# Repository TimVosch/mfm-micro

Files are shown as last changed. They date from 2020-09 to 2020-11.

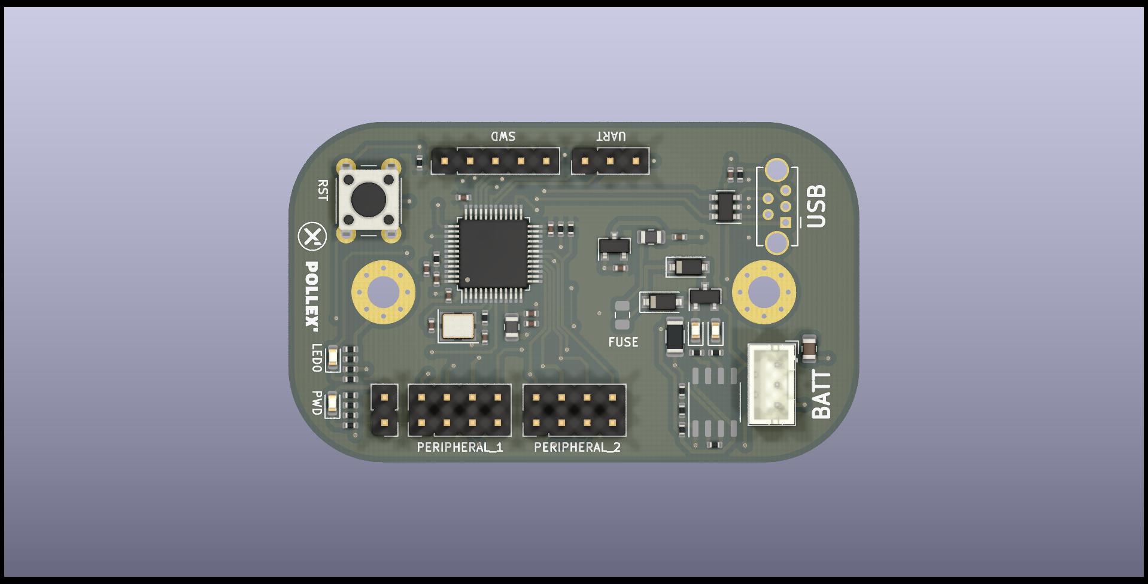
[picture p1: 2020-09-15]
hardware/export/pcb_front.jpg

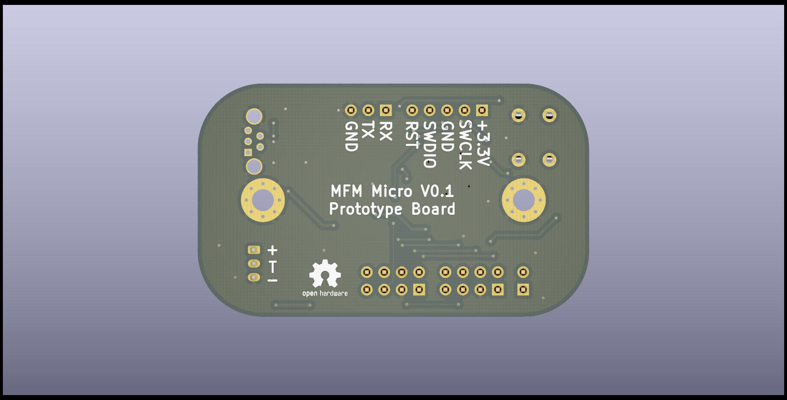
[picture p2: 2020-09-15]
hardware/export/pcb_back.jpg

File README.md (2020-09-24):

# Multiflexmeter Micro

A small, long lasting measurement device with hotswappable zero-configuration peripherals.

## Hardware development

Developed using KiCAD. Files are in the `hardware` folder.

## Firmware development

Developed using PlatformIO and the STM32CubeL0 library with CMSIS.

```
git clone https://github.com/TimVosch/mfm-micro.git
cd mfm-micro
git submodule update --init
```

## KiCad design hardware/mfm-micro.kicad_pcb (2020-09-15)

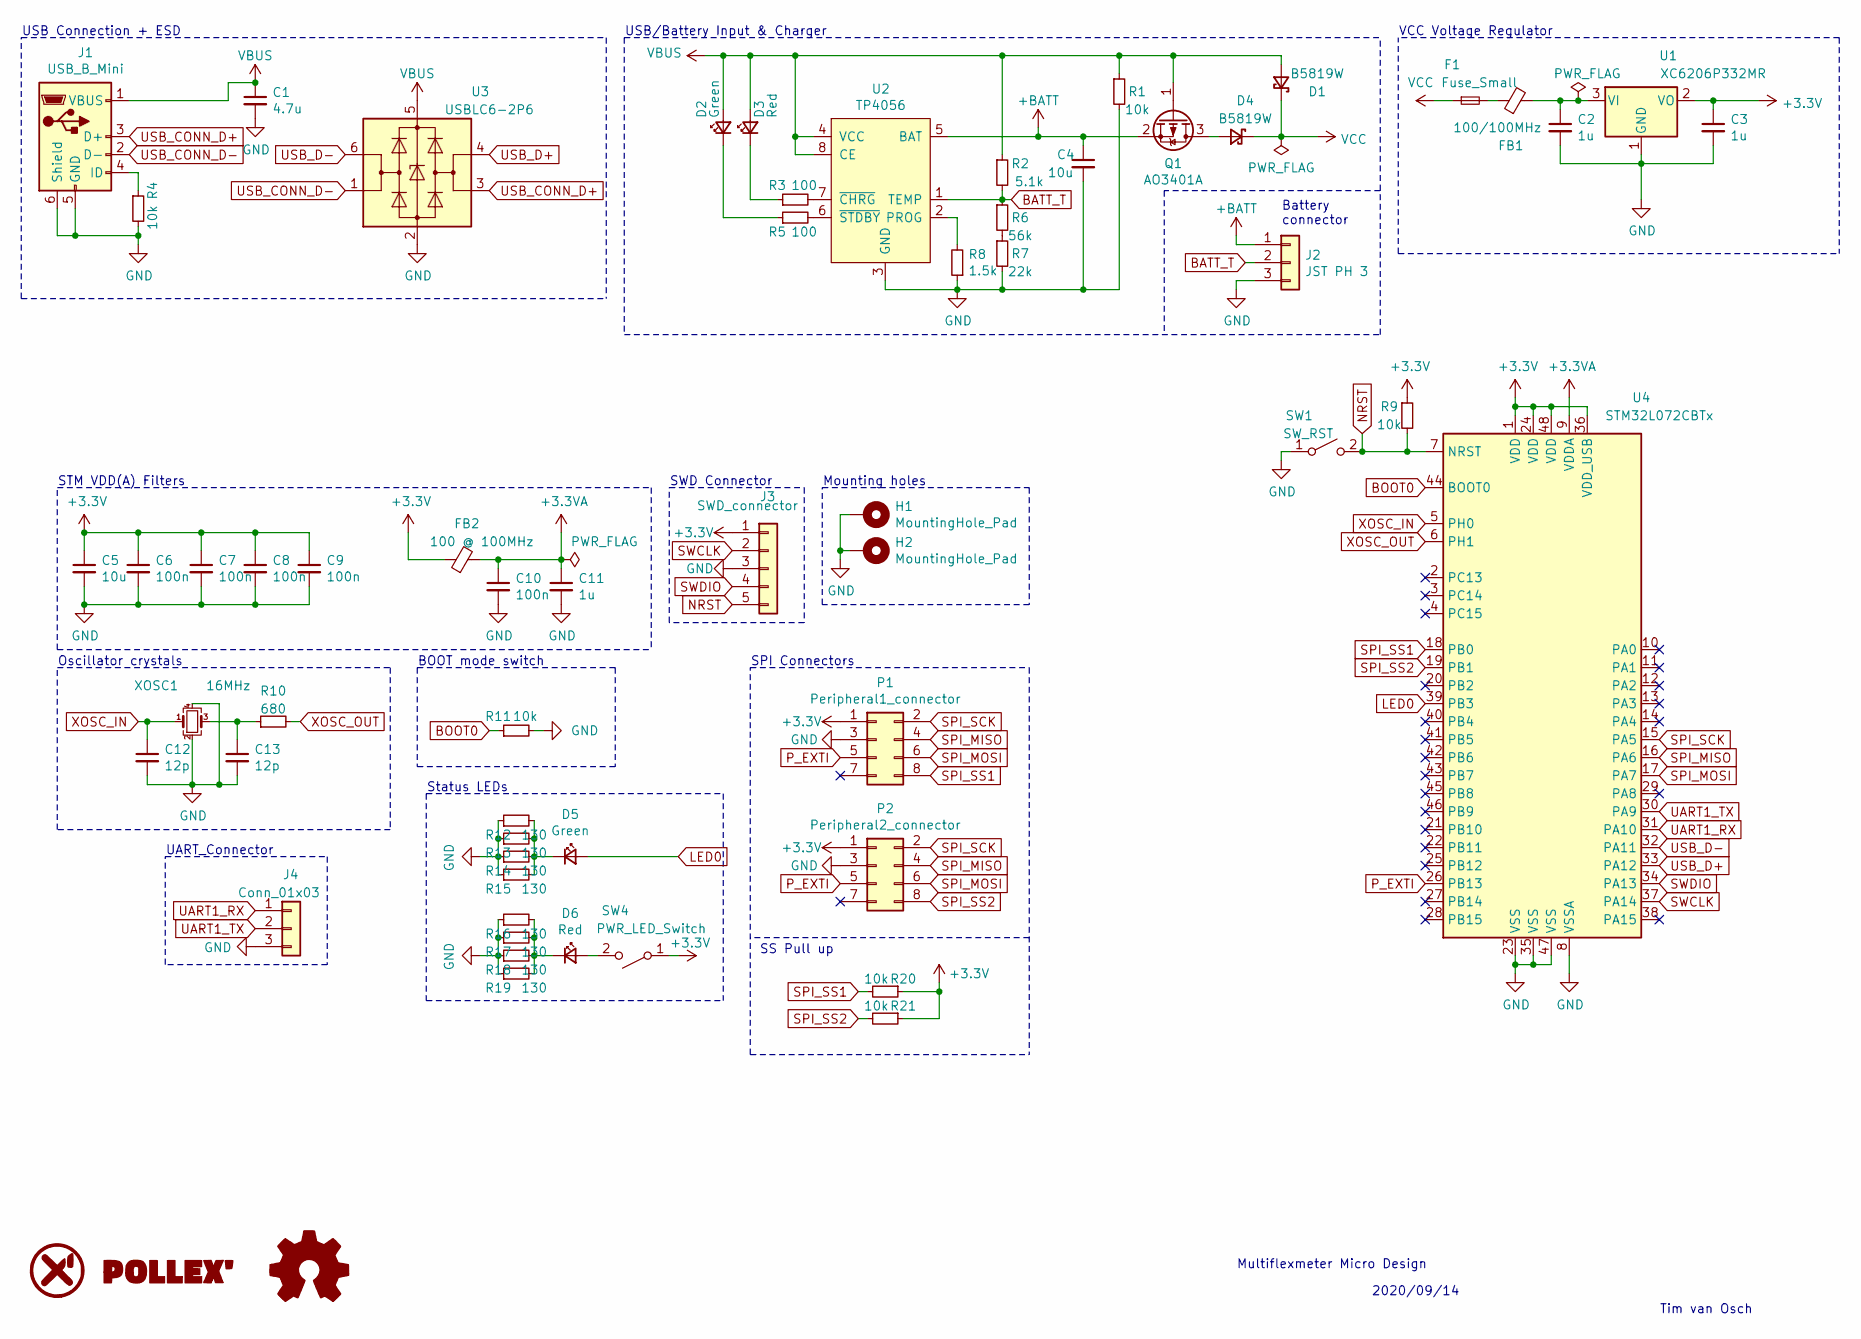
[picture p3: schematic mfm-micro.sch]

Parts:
C1: 4.7u; C_0402_1005Metric
C2, C3, C11: 1u; C_0402_1005Metric
C4: 10u; C_0805_2012Metric
C5: 10u; C_0402_1005Metric
C6, C7, C8, C9, C10: 100n; C_0402_1005Metric
C12, C13: 12p; C_0402_1005Metric
D1, D4: B5819W; D_SOD-123
D2, D5: Green; LED_0603_1608Metric
D3, D6: Red; LED_0603_1608Metric
F1: Fuse_Small; Fuse_0805_2012Metric
FB1: 100/100MHz; L_0805_2012Metric
FB2: 100 @ 100MHz; L_0805_2012Metric
H1, H2: MountingHole_Pad; MountingHole_3.2mm_M3_Pad_Via
J1: USB_B_Mini; USB_Mini-B_Tensility_54-00023_Vertical_CircularHoles
J2: JST PH 3; JST_PH_B3B-PH-K_1x03_P2.00mm_Vertical
J3: SWD_connector; PinHeader_1x05_P2.54mm_Vertical
J4: Conn_01x03; PinHeader_1x03_P2.54mm_Vertical
P1: Peripheral1_connector; PinHeader_2x04_P2.54mm_Vertical
P2: Peripheral2_connector; PinHeader_2x04_P2.54mm_Vertical
Q1: AO3401A; SOT-23
R1: 10k; R_1206_3216Metric
R2: 5.1k; R_0402_1005Metric
R3, R5: 100; R_0402_1005Metric
R4, R9, R11, R20, R21: 10k; R_0402_1005Metric
R6: 56k; R_0402_1005Metric
R7: 22k; R_0402_1005Metric
R8: 1.5k; R_0402_1005Metric
R10: 680; R_0402_1005Metric
R12, R13, R14, R15, R16, R17, R18, R19: 130; R_0402_1005Metric
SW1: SW_RST; SW_PUSH_6mm
SW4: PWR_LED_Switch; PinHeader_1x02_P2.54mm_Vertical
U1: XC6206P332MR; SOT-23
U2: TP4056; SOP-8_3.9x4.9mm_P1.27mm
U3: USBLC6-2P6; SOT-23-6
U4: STM32L072CBTx; LQFP-48_7x7mm_P0.5mm
XOSC1: 16MHz; Crystal_SMD_3225-4Pin_3.2x2.5mm

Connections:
+3.3VA: C10.1, C11.1, FB2.2, U4.9 (VDDA)
+3V3: C3.1, C5.1, C6.1, C7.1, C8.1, C9.1, FB2.1, J3.1, P1.1, P2.1, R9.1, R20.1, R21.1, SW4.1 (A), U1.2 (VO), U4.1 (VDD), U4.24 (VDD), U4.36 (VDD_USB), U4.48 (VDD)
+BATT: C4.1, J2.1, Q1.2 (S), U2.5 (BAT)
BATT_T: J2.2, R2.2, R6.1, U2.1 (TEMP)
BOOT0: R11.1, U4.44 (BOOT0)
GND: C1.2, C2.2, C3.2, C4.2, C5.2, C6.2, C7.2, C8.2, C9.2, C10.2, C11.2, C12.2, C13.2, H1.1, H2.1, J1.5 (GND), J1.6 (Shield), J2.3, J3.3, J4.3, P1.3, P2.3, R1.2, R4.2, R7.2, R8.1, R11.2, R12.1, R13.1, R14.1, R15.1, R16.1, R17.1, R18.1, R19.1, SW1.1 (A), U1.1 (GND), U2.3 (GND), U3.2 (GND), U4.8 (VSSA), U4.23 (VSS), U4.35 (VSS), U4.47 (VSS), XOSC1.2, XOSC1.4
LED0: D5.2 (A), U4.39 (PB3)
NRST: J3.5, R9.2, SW1.2 (B), U4.7 (NRST)
unnamed: C2.1, FB1.2, U1.3 (VI)
unnamed: C13.1, R10.1, XOSC1.3
unnamed: D2.1 (K), R5.1
unnamed: D3.1 (K), R3.1
unnamed: D4.2 (A), Q1.3 (D)
unnamed: D5.1 (K), R12.2, R13.2, R14.2, R15.2
unnamed: D6.1 (K), R16.2, R17.2, R18.2, R19.2
unnamed: D6.2 (A), SW4.2 (B)
unnamed: F1.2, FB1.1
unnamed: J1.4 (ID), R4.1
unnamed: R3.2, U2.7 (~CHRG)
unnamed: R5.2, U2.6 (~STDBY)
unnamed: R6.2, R7.1
unnamed: R8.2, U2.2 (PROG)
P_EXTI: P1.5, P2.5, U4.26 (PB13)
SPI_MISO: P1.4, P2.4, U4.16 (PA6)
SPI_MOSI: P1.6, P2.6, U4.17 (PA7)
SPI_SCK: P1.2, P2.2, U4.15 (PA5)
SPI_SS1: P1.8, R20.2, U4.18 (PB0)
SPI_SS2: P2.8, R21.2, U4.19 (PB1)
SWCLK: J3.2, U4.37 (PA14)
SWDIO: J3.4, U4.34 (PA13)
UART1_RX: J4.1, U4.31 (PA10)
UART1_TX: J4.2, U4.30 (PA9)
USB_CONN_D+: J1.3 (D+), U3.3 (I/O2)
USB_CONN_D-: J1.2 (D-), U3.1 (I/O1)
USB_D+: U3.4 (I/O2), U4.33 (PA12)
USB_D-: U3.6 (I/O1), U4.32 (PA11)
VBUS: C1.1, D1.2 (A), D2.2 (A), D3.2 (A), J1.1 (VBUS), Q1.1 (G), R1.1, R2.1, U2.4 (VCC), U2.8 (CE), U3.5 (VBUS)
VCC: D1.1 (K), D4.1 (K), F1.1
XOSC_IN: C12.1, U4.5 (PH0), XOSC1.1
XOSC_OUT: R10.2, U4.6 (PH1)

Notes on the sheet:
VCC Voltage Regulator
USB Connection + ESD
Battery connector
USB/Battery Input & Charger
SPI Connectors
Status LEDs
BOOT mode switch
Oscillator crystals
STM VDD(A) Filters
SS Pull up
Multiflexmeter Micro Design
2020/09/14
Tim van Osch
Mounting holes
SWD Connector
UART_Connector

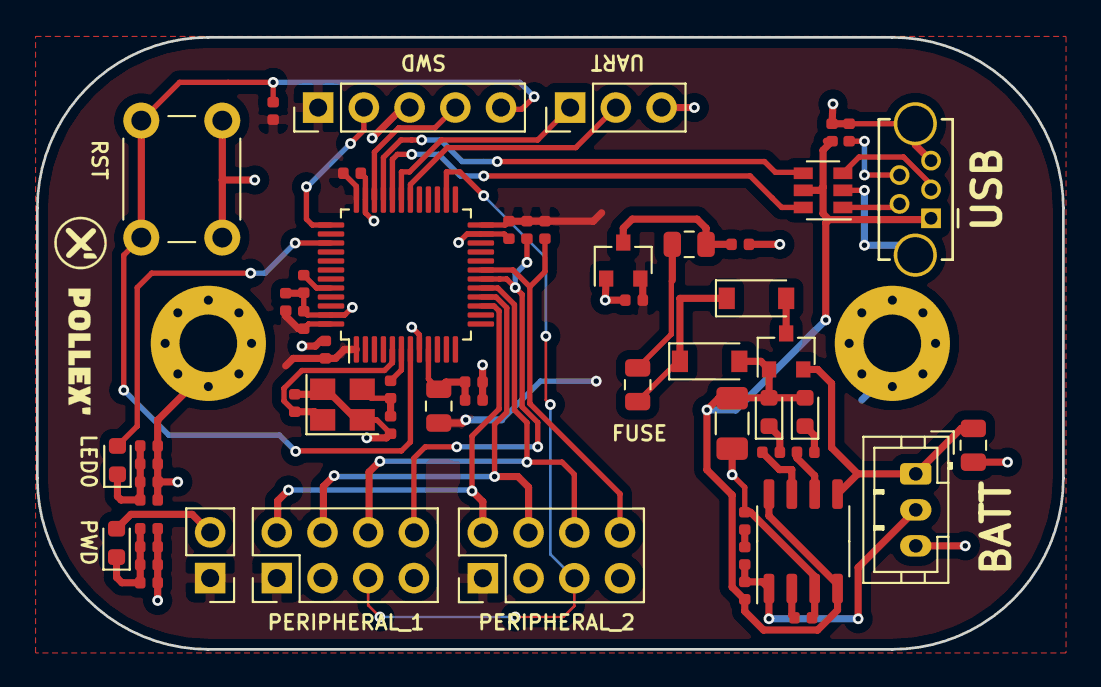
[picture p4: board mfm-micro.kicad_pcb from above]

Board: 4 copper layers, 57.0 x 34.0 mm, 59 parts (0 on the bottom side), 40 nets.

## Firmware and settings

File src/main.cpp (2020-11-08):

#include "main.hpp"
#include "drivers/i2c_timing.hpp"
#include "drivers/i2c_master.hpp"
#include "drivers/smbus.hpp"

void gpio_init()
{
  // Enable GPIO CLK
  __HAL_RCC_GPIOA_CLK_ENABLE();
  __HAL_RCC_GPIOB_CLK_ENABLE();

  GPIO_InitTypeDef GPIO_LED = {0};
  GPIO_LED.Pin = LED0_Pin;
  GPIO_LED.Mode = GPIO_MODE_OUTPUT_PP;
  GPIO_LED.Speed = GPIO_SPEED_FAST;
  GPIO_LED.Pull = GPIO_NOPULL;
  HAL_GPIO_Init(LED0_Port, &GPIO_LED);

  // ---- Initialize I2C GPIO pins ----
  // Init SCL to OpenDrain
  GPIO_InitTypeDef scl_init = {0};
  scl_init.Pin = I2C_SCL_Pin;
  scl_init.Mode = GPIO_MODE_OUTPUT_OD;
  scl_init.Speed = GPIO_SPEED_FAST;
  scl_init.Pull = GPIO_NOPULL;
  HAL_GPIO_Init(I2C_SCL_Port, &scl_init);

  // Init SDA to OpenDrain
  GPIO_InitTypeDef sda_init = {0};
  sda_init.Pin = I2C_SDA_Pin;
  sda_init.Mode = GPIO_MODE_OUTPUT_OD;
  sda_init.Speed = GPIO_SPEED_FAST;
  sda_init.Pull = GPIO_NOPULL;
  HAL_GPIO_Init(I2C_SDA_Port, &sda_init);

  // Default high
  HAL_GPIO_WritePin(I2C_SDA_Port, I2C_SDA_Pin, GPIO_PIN_SET);
  HAL_GPIO_WritePin(I2C_SCL_Port, I2C_SCL_Pin, GPIO_PIN_SET);
}

void crc_init()
{
  __HAL_RCC_CRC_CLK_ENABLE();
}

void timer_init()
{
  // Set TIMER 6 to us
  uint8_t psc = SystemCoreClock / 1e6 - 1;
  __HAL_RCC_TIM6_CLK_ENABLE();
  TIM6->SR = 0;
  TIM6->PSC = psc;
  TIM6->CR1 = TIM_CR1_UDIS;
  TIM6->CR1 = TIM_CR1_CEN;
}

/**
  * @brief System Clock Configuration
  * @retval None
  */
void SystemClock_Config(void)
{
  RCC_OscInitTypeDef RCC_OscInitStruct = {0};
  RCC_ClkInitTypeDef RCC_ClkInitStruct = {0};

  /** Configure the main internal regulator output voltage
  */
  __HAL_PWR_VOLTAGESCALING_CONFIG(PWR_REGULATOR_VOLTAGE_SCALE1);
  /** Initializes the RCC Oscillators according to the specified parameters
  * in the RCC_OscInitTypeDef structure.
  */
  RCC_OscInitStruct.OscillatorType = RCC_OSCILLATORTYPE_HSE;
  RCC_OscInitStruct.HSEState = RCC_HSE_ON;
  RCC_OscInitStruct.HSIState = RCC_HSI_OFF;
  RCC_OscInitStruct.MSIState = RCC_MSI_OFF;
  RCC_OscInitStruct.HSICalibrationValue = 0;
  RCC_OscInitStruct.PLL.PLLState = RCC_PLL_NONE;
  if (HAL_RCC_OscConfig(&RCC_OscInitStruct) != HAL_OK)
  {
    Error_Handler();
  }
  /** Initializes the CPU, AHB and APB buses clocks
  */
  RCC_ClkInitStruct.ClockType = RCC_CLOCKTYPE_HCLK | RCC_CLOCKTYPE_SYSCLK | RCC_CLOCKTYPE_PCLK1 | RCC_CLOCKTYPE_PCLK2;
  RCC_ClkInitStruct.SYSCLKSource = RCC_SYSCLKSOURCE_HSE;
  RCC_ClkInitStruct.AHBCLKDivider = RCC_SYSCLK_DIV1;
  RCC_ClkInitStruct.APB1CLKDivider = RCC_HCLK_DIV1;
  RCC_ClkInitStruct.APB2CLKDivider = RCC_HCLK_DIV1;

  if (HAL_RCC_ClockConfig(&RCC_ClkInitStruct, FLASH_LATENCY_0) != HAL_OK)
  {
    Error_Handler();
  }
  SystemCoreClockUpdate();
}

int main(void)
{
  SystemClock_Config();
  HAL_Init();
  gpio_init();
  timer_init();
  crc_init();

  I2C_TIMING standard = I2C_TIMING_STANDARD;
  I2C_Master i2c(I2C_SCL_Pin, I2C_SCL_Port, I2C_SDA_Pin, I2C_SDA_Port, &standard);
  SMBus smbus(&i2c);

  smbus.select(0x70);
  for (;;)
  {
    uint8_t data;
    auto res = smbus.receive_byte(&data);
    if (res == SMBUS_STATUS_PEC_FAIL)
    {
      HAL_GPIO_TogglePin(LED0_Port, LED0_Pin);
    }

    HAL_Delay(1000);
  }
}

void Error_Handler(void)
{
  for (;;)
    ;
}

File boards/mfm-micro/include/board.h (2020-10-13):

#if !defined(_BOARD_H_)
#define _BOARD_H_

#include <stm32l0xx_hal.h>
#include <stm32l0xx_hal_gpio.h>

/*
  Pin definitions
*/

#define LED0_Pin GPIO_PIN_3
#define LED0_Port GPIOB

/*
  Peripheral I2C definitions
*/

#define I2C_SCL_Port GPIOA
#define I2C_SCL_Pin GPIO_PIN_5
#define I2C_SDA_Port GPIOA
#define I2C_SDA_Pin GPIO_PIN_6

/*
  Peripheral SPI definitions
*/

// #define PERIPHERAL_SPI_AF GPIO_AF0_SPI1
// #define PERIPHERAL_SPI_Instance SPI1
// #define PERIPHERAL_SPI_Port GPIOA

// #define PERIPHERAL_SCK_Pin GPIO_PIN_5
// #define PERIPHERAL_MISO_Pin GPIO_PIN_6
// #define PERIPHERAL_MOSI_Pin GPIO_PIN_7

// #define PERIPHERAL_INT_Pin GPIO_PIN_13
// #define PERIPHERAL_INT_Port GPIOB

// #define PERIPHERAL1_NSS_Pin GPIO_PIN_0
// #define PERIPHERAL1_NSS_Port GPIOB

// #define PERIPHERAL2_NSS_Pin GPIO_PIN_1
// #define PERIPHERAL2_NSS_Port GPIOB

#endif

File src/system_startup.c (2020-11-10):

#include <stdint.h>
#include <stm32l0xx_hal.h>
#define _estack 0x20005000
#define weak_alias(old, new) \
  extern __typeof(old) new __attribute__((weak, alias(#old)))

extern unsigned int _sidata;
extern unsigned int _sdata;
extern unsigned int _edata;
extern unsigned int _sbss;
extern unsigned int _ebss;

void Reset_Handler();
void Default_Handler();
void SystemInit();
void __libc_init_array();
void main();

weak_alias(Default_Handler, NMI_Handler);
weak_alias(Default_Handler, HardFault_Handler);
weak_alias(Default_Handler, SVC_Handler);
weak_alias(Default_Handler, PendSV_Handler);
weak_alias(Default_Handler, SysTick_Handler);
weak_alias(Default_Handler, WWDG_IRQHandler);
weak_alias(Default_Handler, PVD_IRQHandler);
weak_alias(Default_Handler, RTC_IRQHandler);
weak_alias(Default_Handler, FLASH_IRQHandler);
weak_alias(Default_Handler, RCC_CRS_IRQHandler);
weak_alias(Default_Handler, EXTI0_1_IRQHandler);
weak_alias(Default_Handler, EXTI2_3_IRQHandler);
weak_alias(Default_Handler, EXTI4_15_IRQHandler);
weak_alias(Default_Handler, TSC_IRQHandler);
weak_alias(Default_Handler, DMA1_Channel1_IRQHandler);
weak_alias(Default_Handler, DMA1_Channel2_3_IRQHandler);
weak_alias(Default_Handler, DMA1_Channel4_5_6_7_IRQHandler);
weak_alias(Default_Handler, ADC1_COMP_IRQHandler);
weak_alias(Default_Handler, LPTIM1_IRQHandler);
weak_alias(Default_Handler, USART4_5_IRQHandler);
weak_alias(Default_Handler, TIM2_IRQHandler);
weak_alias(Default_Handler, TIM3_IRQHandler);
weak_alias(Default_Handler, TIM6_DAC_IRQHandler);
weak_alias(Default_Handler, TIM7_IRQHandler);
weak_alias(Default_Handler, TIM21_IRQHandler);
weak_alias(Default_Handler, I2C3_IRQHandler);
weak_alias(Default_Handler, TIM22_IRQHandler);
weak_alias(Default_Handler, I2C1_IRQHandler);
weak_alias(Default_Handler, I2C2_IRQHandler);
weak_alias(Default_Handler, SPI1_IRQHandler);
weak_alias(Default_Handler, SPI2_IRQHandler);
weak_alias(Default_Handler, USART1_IRQHandler);
weak_alias(Default_Handler, USART2_IRQHandler);
weak_alias(Default_Handler, RNG_LPUART1_IRQHandler);
weak_alias(Default_Handler, USB_IRQHandler);

unsigned int *vectorTable[48] __attribute__((section(".isr_vector"))) = {
    (unsigned int *)_estack,
    (unsigned int *)Reset_Handler,
    (unsigned int *)NMI_Handler,
    (unsigned int *)HardFault_Handler,
    (unsigned int *)0,
    (unsigned int *)0,
    (unsigned int *)0,
    (unsigned int *)0,
    (unsigned int *)0,
    (unsigned int *)0,
    (unsigned int *)0,
    (unsigned int *)SVC_Handler,
    (unsigned int *)0,
    (unsigned int *)0,
    (unsigned int *)PendSV_Handler,
    (unsigned int *)SysTick_Handler,
    (unsigned int *)WWDG_IRQHandler,                /* Window WatchDog              */
    (unsigned int *)PVD_IRQHandler,                 /* PVD through EXTI Line detection */
    (unsigned int *)RTC_IRQHandler,                 /* RTC through the EXTI line     */
    (unsigned int *)FLASH_IRQHandler,               /* FLASH                        */
    (unsigned int *)RCC_CRS_IRQHandler,             /* RCC and CRS                  */
    (unsigned int *)EXTI0_1_IRQHandler,             /* EXTI Line 0 and 1            */
    (unsigned int *)EXTI2_3_IRQHandler,             /* EXTI Line 2 and 3            */
    (unsigned int *)EXTI4_15_IRQHandler,            /* EXTI Line 4 to 15            */
    (unsigned int *)TSC_IRQHandler,                 /* TSC                           */
    (unsigned int *)DMA1_Channel1_IRQHandler,       /* DMA1 Channel 1               */
    (unsigned int *)DMA1_Channel2_3_IRQHandler,     /* DMA1 Channel 2 and Channel 3 */
    (unsigned int *)DMA1_Channel4_5_6_7_IRQHandler, /* DMA1 Channel 4, Channel 5, Channel 6 and Channel 7*/
    (unsigned int *)ADC1_COMP_IRQHandler,           /* ADC1, COMP1 and COMP2        */
    (unsigned int *)LPTIM1_IRQHandler,              /* LPTIM1                       */
    (unsigned int *)USART4_5_IRQHandler,            /* USART4 and USART 5           */
    (unsigned int *)TIM2_IRQHandler,                /* TIM2                         */
    (unsigned int *)TIM3_IRQHandler,                /* TIM3                         */
    (unsigned int *)TIM6_DAC_IRQHandler,            /* TIM6 and DAC                 */
    (unsigned int *)TIM7_IRQHandler,                /* TIM7                         */
    (unsigned int *)0,                              /* Reserved                     */
    (unsigned int *)TIM21_IRQHandler,               /* TIM21                        */
    (unsigned int *)I2C3_IRQHandler,                /* I2C3                         */
    (unsigned int *)TIM22_IRQHandler,               /* TIM22                        */
    (unsigned int *)I2C1_IRQHandler,                /* I2C1                         */
    (unsigned int *)I2C2_IRQHandler,                /* I2C2                         */
    (unsigned int *)SPI1_IRQHandler,                /* SPI1                         */
    (unsigned int *)SPI2_IRQHandler,                /* SPI2                         */
    (unsigned int *)USART1_IRQHandler,              /* USART1                       */
    (unsigned int *)USART2_IRQHandler,              /* USART2                       */
    (unsigned int *)RNG_LPUART1_IRQHandler,         /* RNG and LPUART1              */
    (unsigned int *)0,                              /* Reserved                     */
    (unsigned int *)USB_IRQHandler,                 /* USB                          */
};

void Default_Handler()
{
  for (;;)
    ;
}

typedef void pFunc(void);
void Reset_Handler()
{
  unsigned int *data_rom_start_p = &_sidata;
  unsigned int *data_ram_start_p = &_sdata;
  unsigned int *data_ram_end_p = &_edata;

  unsigned int *_bss_start_p = &_sbss;
  unsigned int *_bss_end_p = &_ebss;
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

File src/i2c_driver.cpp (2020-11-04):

#include "i2c_driver.hpp"

void init_timer()
{
  // Set TIMER 6 to us
  uint8_t psc = SystemCoreClock / 1e6 - 1;
  __HAL_RCC_TIM6_CLK_ENABLE();
  TIM6->SR = 0;
  TIM6->PSC = psc;
  TIM6->CR1 = TIM_CR1_UDIS;
  TIM6->CR1 = TIM_CR1_CEN;
}

void delay_us(uint16_t us)
{
  TIM6->CNT = 0;
  while (TIM6->CNT < us)
    ;
}

//
// ---- Utility functions ----
//
GPIO_PinState I2CDriver::read_sda()
{
  return HAL_GPIO_ReadPin(this->SDA_Port, this->SDA_Pin);
}
GPIO_PinState I2CDriver::read_scl()
{
  return HAL_GPIO_ReadPin(this->SCL_Port, this->SCL_Pin);
}
void I2CDriver::sda_high()
{
  HAL_GPIO_WritePin(this->SDA_Port, this->SDA_Pin, GPIO_PIN_SET);
}
void I2CDriver::scl_high()
{
  HAL_GPIO_WritePin(this->SCL_Port, this->SCL_Pin, GPIO_PIN_SET);
}
void I2CDriver::sda_low()
{
  HAL_GPIO_WritePin(this->SDA_Port, this->SDA_Pin, GPIO_PIN_RESET);
}
void I2CDriver::scl_low()
{
  HAL_GPIO_WritePin(this->SCL_Port, this->SCL_Pin, GPIO_PIN_RESET);
}

//
// ---- private functions ----
//

/**
 * Wait for SCL to go high
 */
void I2CDriver::clock_stretch()
{
  // Wait for clock to go high
  // or the timeout timer to trigger
  TIM6->SR = 0;
  // TIM6->ARR = timing->clock_stretch;
  TIM6->ARR = 0xFF;
  TIM6->CNT = 0;
  TIM6->CR1 |= TIM_CR1_CEN;
  while (!read_scl() && !(TIM6->SR & TIM_SR_UIF))
    ;
}

void I2CDriver::start_condition(bool restart)
{
  // Repeated start
  if (restart)
  {
    sda_high();
    scl_high();
    delay_us(timing->start_repeat_setup);
  }

  // Start condition
  sda_low();
  delay_us(timing->start_hold);
  scl_low();
}

void I2CDriver::stop_condition()
{
  sda_low();
  scl_high();
  delay_us(timing->stop_setup);
  sda_high();

  // Avoid buslock condition
  delay_us(timing->bus_free / 2);
  if (!read_scl() || !read_sda())
  {
    for (uint8_t i = 0; i < 8; i++)
    {
      scl_high();
      delay_us(timing->high_period);
      scl_low();
      delay_us(timing->low_period);
    }
    scl_high();
  }

  // Update state
  state = I2C_DRIVER_STATE_STOPPED;
}

/**
 * Clock in the 9th clock cycle and read the ack bit
 */
I2C_RESPONSE I2CDriver::get_ack()
{
  // 9th Clock cycle
  sda_high();
  scl_high();
  clock_stretch(); // Allow clock stretching before ack
  delay_us(timing->high_period / 2);
  GPIO_PinState sda = read_sda();
  delay_us(timing->high_period / 2);
  scl_low();
  delay_us(timing->data_hold);

  if (sda == GPIO_PIN_RESET)
  {
    return I2C_RESPONSE_ACK;
  }
  return I2C_RESPONSE_NACK;
}

I2C_RESPONSE I2CDriver::select(uint8_t addr, uint8_t rw)
{
  uint8_t data = (addr << 1) | rw;
  return write(data);
}

//
// ---- Public functions ----
//

void I2CDriver::ack()
{

  // ACk message
  sda_low();
  scl_high();
  delay_us(timing->high_period);
  scl_low();
  sda_high();
}

void I2CDriver::nack()
{
  // ACk message
  sda_high();
  scl_high();
  delay_us(timing->high_period);
  scl_low();
}

I2C_RESPONSE I2CDriver::start(uint8_t addr, I2C_RW rw)
{
  start_condition(false);
  return select(addr, rw);
}

I2C_RESPONSE I2CDriver::restart(uint8_t addr, I2C_RW rw)
{
  start_condition(true);
  return select(addr, rw);
}

void I2CDriver::stop()
{
  stop_condition();
}

/**
 * @brief Write a byte to the slave
 * 
 * @param byte The byte to send
 * @return I2C_RESPONSE
 */
I2C_RESPONSE I2CDriver::write(uint8_t data)
{
  // Send 8 bits
  for (int i = 0; i < 8; i++)
  {
    // Setup data line
    if (data & 0x80)
    {
      sda_high();
    }
    else
    {
      sda_low();
    }
    data <<= 1;

    // Clock in data
    delay_us(timing->data_setup);
    scl_high();
    delay_us(timing->high_period);
    scl_low();
    delay_us(timing->data_hold);
  }

  // Get the Acknowledgement bit
  return get_ack();
}

/**
 * @brief Read a byte from the slave
 * 
 * @param byte The byte to send
 * @return I2C_RESPONSE
 */
uint8_t I2CDriver::read()
{
  uint8_t data = 0;
  for (uint8_t bit_pos = 8; bit_pos > 0; bit_pos--)
  {
    delay_us(timing->low_period);
    scl_high();
    clock_stretch();

    // Insert high bit
    if (read_sda())
    {
      data |= 1 << (bit_pos - 1);
    }
    delay_us(timing->high_period);
    scl_low();
  }

  return data;
}

//
// (De)constructor
//

I2CDriver::I2CDriver(uint32_t SCL_Pin,
                     GPIO_TypeDef *SCL_Port,
                     uint32_t SDA_Pin,
                     GPIO_TypeDef *SDA_Port,
                     I2C_TIMING *timing) : SCL_Pin{SCL_Pin},
                                           SCL_Port{SCL_Port},
                                           SDA_Pin{SDA_Pin},
                                           SDA_Port{SDA_Port},
                                           timing{timing},
                                           state{I2C_DRIVER_STATE_STOPPED}
{
  init_timer();
}
I2CDriver::~I2CDriver()
{
}

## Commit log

2020-09-14 Place components on PCB
    [mfm-micro.kicad_pcb, mfm-micro.sch]
2020-09-15 Rerout and new exports
    [mfm-micro-1.kicad_pcb, mfm-micro.kicad_pcb, mfm-micro.sch]
2020-09-24 Reorganize project structure
    [mfm-micro-1.kicad_pcb, mfm-micro.kicad_pcb, mfm-micro.sch]
2020-09-28 Use stm32 generated lib
2020-09-29 SPI test
2020-10-13 feat: Implement I2C BitBang single byte write
2020-10-14 feat(I2C): Swap and implement write for byte array
    Rename function to function and implement writing a
    byte array in new func
    [i2c_driver.cpp, main.cpp]
2020-10-15 Refactor: update i2c driver
2020-10-26 refactor(i2c): rename sda/scl clear/set to low/high
2020-11-04 Update docs
    [mfm-micro.sch]
2020-11-04 Update I2C driver functions
2020-11-06 Move to drivers folder, direct IO register access
2020-11-06 Refactor i2c_driver.cpp to i2c.cpp
2020-11-06 refactor(u2c/smbus): Move write/read bytes to i2c driver
    Moves the i2c_read_bytes and i2c_write_bytes functions from the smbus
    driver to the i2c driver as read_bytes and write_bytes respectively
2020-11-06 fix(smbus): Allow quick-command 1 or 0
    Previous implementation only allowed to send a write bit (one), however
    this bit can also be read bit (zero)
    [smbus.cpp]
2020-11-07 style(i2c): Comments
2020-11-07 feat(smbus): I2CDriver wrapper for SMBus
    Provides a new SMBus_I2C class which is just like the I2CDriver except
    also calculates the CRC for messages
2020-11-07 feat(smbus): SMBus_I2C hold R/W direction and pending ACK
    The SMBus_I2C wrapper now holds the current transaction direction and
    whether there is an acknowledgement pending.
    The pending ack is only applicable when reading bytes, because written
    bytes are acked in the I2CDriver
2020-11-07 feat(smbus): getters for cur_dir and pend_ack in SMBus_I2C
    Rename pend_ack and cur_dir to pending_ack and current_direction for the
    SMBus_I2C wrapper.
    Also provide getters for both variables.
2020-11-07 refactor(smbus): Use smbus_i2c to rework smubs::end function
    Rework the `end()` function for smbus transactions using the new
    features provided in the smbus_i2c wrapper.
    [smbus.cpp]
2020-11-08 perf(i2c): Improve utility functions
    Remove '> 0' check on read_sda read_scl
    Drop us_delay if delay <= 2 us
2020-11-08 feat(i2c): Allow clock_stretch on each bit
2020-11-08 refactor(i2c): Rename I2CDriver to I2C_Master
2020-11-09 fix(smbus): Have all commands use 'end()'
    [smbus.cpp]
2020-11-10 refactor: Port system_startup assembly to C
2020-11-10 docs(smbus): fix quick_command doc
    [smbus.cpp]
